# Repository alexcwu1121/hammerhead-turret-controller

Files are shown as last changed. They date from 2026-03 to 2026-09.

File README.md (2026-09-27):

# hammerhead-turret-controller

To build:
1. Install Podman >4.x
2. Install VSCode
3. Install VSCode Dev Containers extension
4. In Dev Containers settings, set the following:
    - Docker Path: `podman`
    - Docker Compose Path: `podman-compose`
    - Docker Socket: `/run/podman/podman.sock`

To quick-run pre-commit, builds, tests:
`podman-compose run --build pre-commit`
`podman-compose run --build build-debug`
`podman-compose run --build build-release`

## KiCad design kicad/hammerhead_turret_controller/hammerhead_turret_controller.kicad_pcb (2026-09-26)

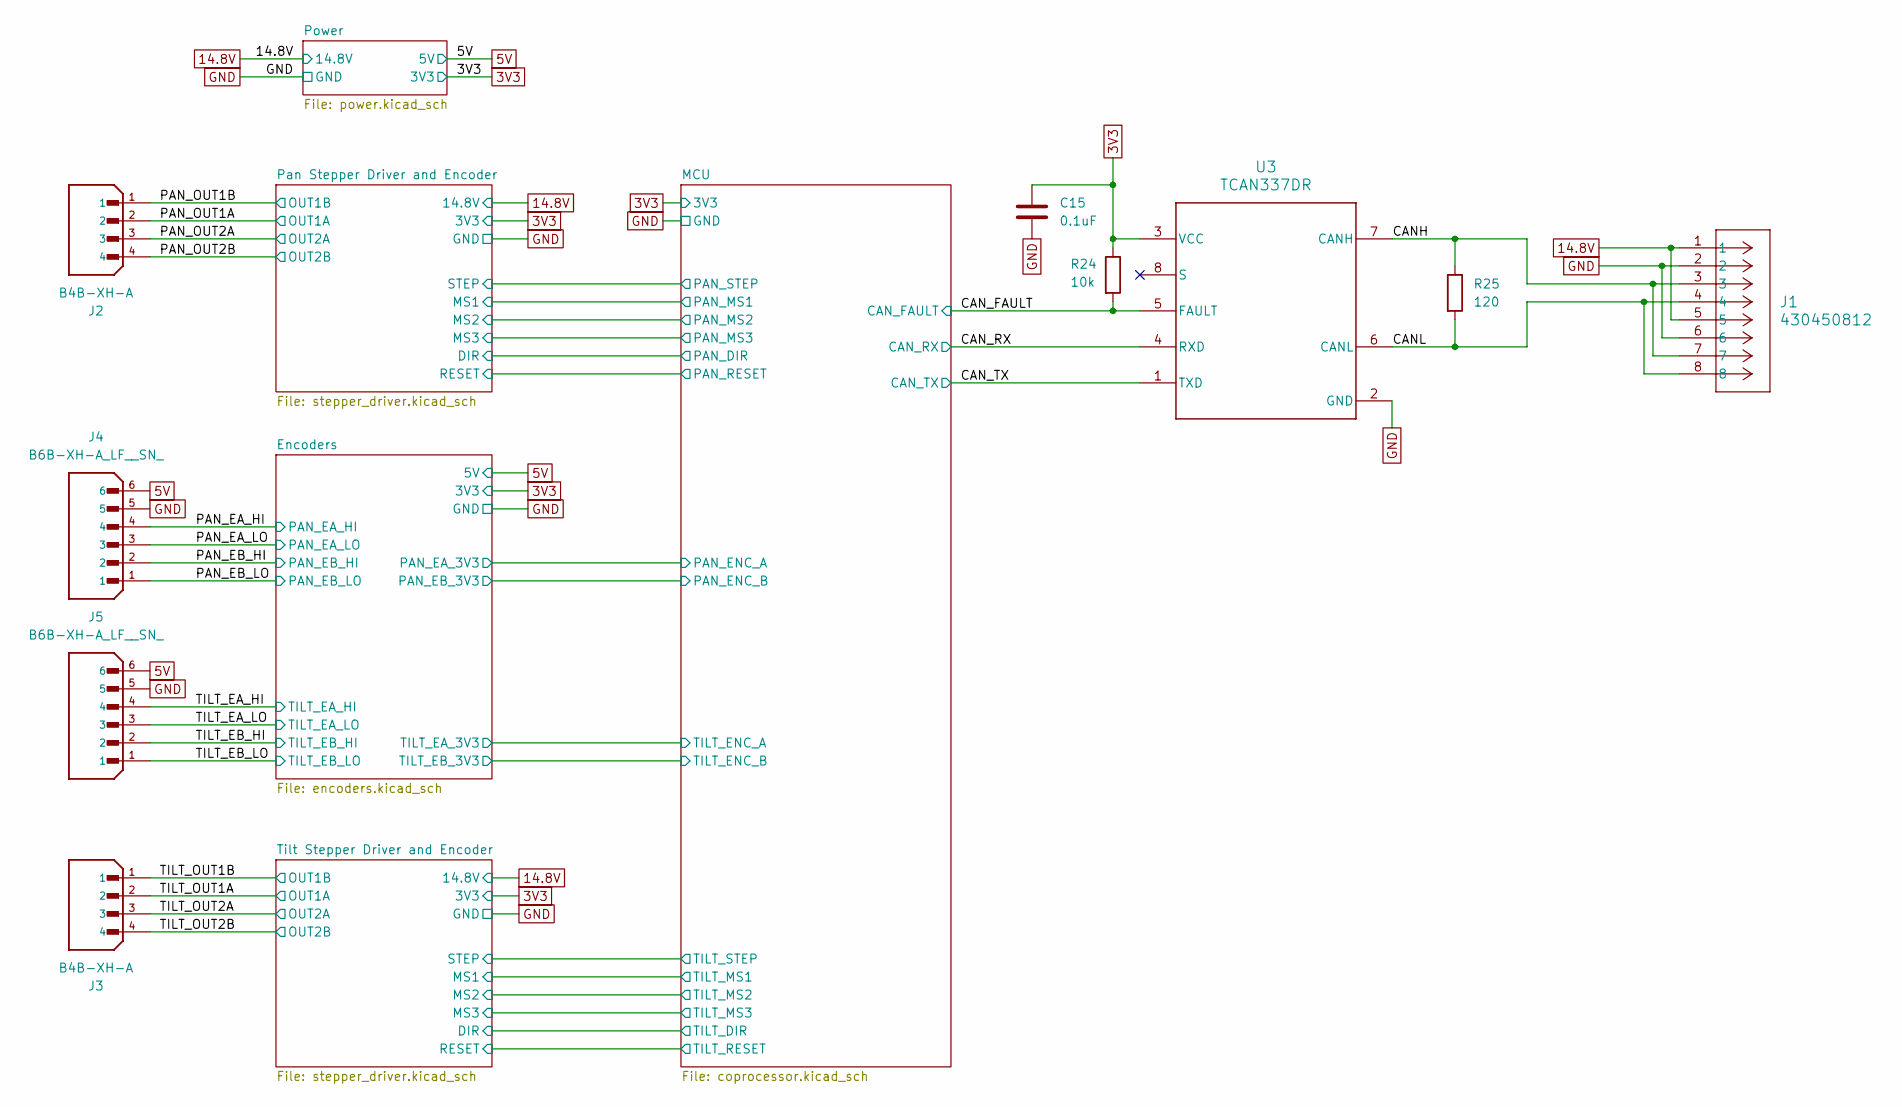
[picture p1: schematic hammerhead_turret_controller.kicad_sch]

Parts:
C15: 0.1uF; C_0402_1005Metric
J1: 430450812; CONN_SD-43045-005_08_MOL
J2, J3: B4B-XH-A; JST_ZH_S4B-ZR-SM4A-TF_1x04-1MP_P1.50mm_Horizontal; PARTREV 7/4/21; DigiKey_Part_Number 455-B4B-XH-A-ND
J4, J5: B6B-XH-A_LF__SN_; JST_ZH_S6B-ZR-SM4A-TF_1x06-1MP_P1.50mm_Horizontal; PARTREV 7/4/21
R24: 10k; R_0402_1005Metric
R25: 120; R_0603_1608Metric
U3: TCAN337DR; D0008A_N

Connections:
3V3: C15.1, R24.1, U3.3 (VCC); also elsewhere on the board
5V: J4.6, J5.6; also elsewhere on the board
14.8V: J1.1, J1.5; also elsewhere on the board
/CANH: J1.3, J1.7, R25.1, U3.7 (CANH)
/CANL: J1.4, J1.8, R25.2, U3.6 (CANL)
/CAN_FAULT: R24.2, U3.5 (FAULT); also elsewhere on the board
/CAN_RX: U3.4 (RXD); also elsewhere on the board
/CAN_TX: U3.1 (TXD); also elsewhere on the board
/PAN_EA_HI: J4.4; also elsewhere on the board
/PAN_EA_LO: J4.3; also elsewhere on the board
/PAN_EB_HI: J4.2; also elsewhere on the board
/PAN_EB_LO: J4.1; also elsewhere on the board
/PAN_OUT1A: J2.2; also elsewhere on the board
/PAN_OUT1B: J2.1; also elsewhere on the board
/PAN_OUT2A: J2.3; also elsewhere on the board
/PAN_OUT2B: J2.4; also elsewhere on the board
/TILT_EA_HI: J5.4; also elsewhere on the board
/TILT_EA_LO: J5.3; also elsewhere on the board
/TILT_EB_HI: J5.2; also elsewhere on the board
/TILT_EB_LO: J5.1; also elsewhere on the board
/TILT_OUT1A: J3.2; also elsewhere on the board
/TILT_OUT1B: J3.1; also elsewhere on the board
/TILT_OUT2A: J3.3; also elsewhere on the board
/TILT_OUT2B: J3.4; also elsewhere on the board
GND: C15.2, J1.2, J1.6, J4.5, J5.5, U3.2 (GND); also elsewhere on the board

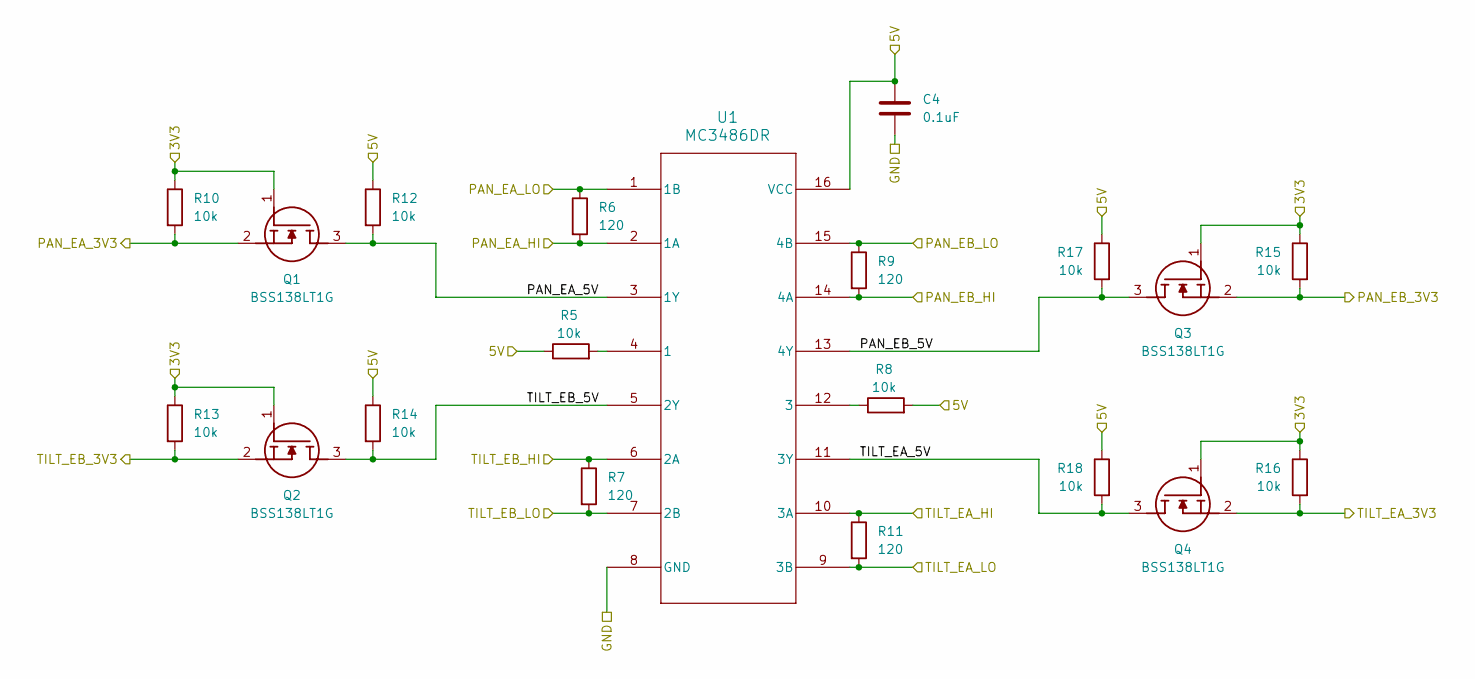
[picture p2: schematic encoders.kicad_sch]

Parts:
C4: 0.1uF; C_0201_0603Metric
Q1, Q2, Q3, Q4: BSS138LT1G; SOT96P237X111-3N; Manufacturer_Part_Number BSS138LT1G; Mouser Part Number 863-BSS138LT1G
R5, R8, R10, R12, R13, R14, R15, R16, R17, R18: 10k; R_0201_0603Metric
R6, R7, R9, R11: 120; R_0201_0603Metric
U1: MC3486DR; D16

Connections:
3V3: Q1.1 (G), Q2.1 (G), Q3.1 (G), Q4.1 (G), R10.1, R13.1, R15.1, R16.1; also elsewhere on the board
5V: C4.2, R5.1, R8.2, R12.1, R14.1, R17.1, R18.1, U1.16 (VCC); also elsewhere on the board
/Encoders/PAN_EA_5V: Q1.3 (D), R12.2, U1.3 (1Y)
/Encoders/PAN_EB_5V: Q3.3 (D), R17.2, U1.13 (4Y)
/Encoders/TILT_EA_5V: Q4.3 (D), R18.2, U1.11 (3Y)
/Encoders/TILT_EB_5V: Q2.3 (D), R14.2, U1.5 (2Y)
/MCU/PAN_ENC_A: Q1.2 (S), R10.2; also elsewhere on the board
/MCU/PAN_ENC_B: Q3.2 (S), R15.2; also elsewhere on the board
/MCU/TILT_ENC_A: Q4.2 (S), R16.2; also elsewhere on the board
/MCU/TILT_ENC_B: Q2.2 (S), R13.2; also elsewhere on the board
/PAN_EA_HI: R6.2, U1.2 (1A); also elsewhere on the board
/PAN_EA_LO: R6.1, U1.1 (1B); also elsewhere on the board
/PAN_EB_HI: R9.2, U1.14 (4A); also elsewhere on the board
/PAN_EB_LO: R9.1, U1.15 (4B); also elsewhere on the board
/TILT_EA_HI: R11.1, U1.10 (3A); also elsewhere on the board
/TILT_EA_LO: R11.2, U1.9 (3B); also elsewhere on the board
/TILT_EB_HI: R7.1, U1.6 (2A); also elsewhere on the board
/TILT_EB_LO: R7.2, U1.7 (2B); also elsewhere on the board
GND: C4.1, U1.8 (GND); also elsewhere on the board
unnamed: R5.2, U1.4 (1)
unnamed: R8.1, U1.12 (3)

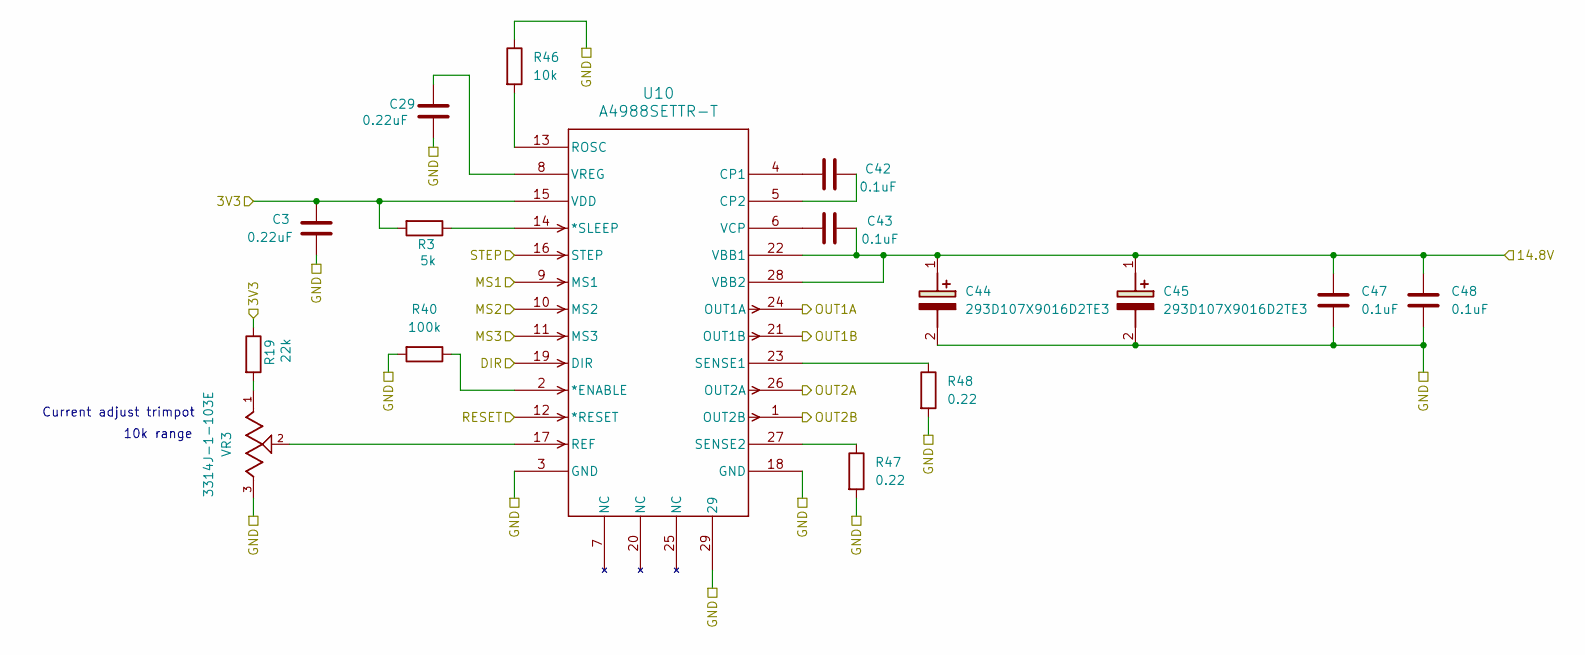
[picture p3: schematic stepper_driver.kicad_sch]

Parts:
C3: 0.22uF; C_0201_0603Metric
C29: 0.22uF; C_0402_1005Metric
C42, C43: 0.1uF; C_0201_0603Metric
C44, C45: 293D107X9016D2TE3; CAPPM7343X310N; Manufacturer_Part_Number 293D107X9016D2TE3; Mouser Part Number 74-293D107X9016D2TE3
C47, C48: 0.1uF; C_0603_1608Metric
R3: 5k; R_0201_0603Metric
R19: 22k; R_0201_0603Metric
R40: 100k; R_0201_0603Metric
R46: 10k; R_0402_1005Metric
R47, R48: 0.22; R_0402_1005Metric
U10: A4988SETTR-T; QFN-28_ALM
VR3: 3314J-1-103E; TRIM_3314J-1-103E

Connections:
3V3: C3.2, R3.2, R19.1, U10.15 (VDD); also elsewhere on the board
14.8V: C43.2, C44.1 (+), C45.1 (+), C47.1, C48.1, U10.22 (VBB1), U10.28 (VBB2); also elsewhere on the board
/MCU/PAN_DIR: U10.19 (DIR); also elsewhere on the board
/MCU/PAN_MS1: U10.9 (MS1); also elsewhere on the board
/MCU/PAN_MS2: U10.10 (MS2); also elsewhere on the board
/MCU/PAN_MS3: U10.11 (MS3); also elsewhere on the board
/MCU/PAN_RESET: U10.12 (*RESET); also elsewhere on the board
/MCU/PAN_STEP: U10.16 (STEP); also elsewhere on the board
/PAN_OUT1A: U10.24 (OUT1A); also elsewhere on the board
/PAN_OUT1B: U10.21 (OUT1B); also elsewhere on the board
/PAN_OUT2A: U10.26 (OUT2A); also elsewhere on the board
/PAN_OUT2B: U10.1 (OUT2B); also elsewhere on the board
GND: C3.1, C29.2, C44.2 (-), C45.2 (-), C47.2, C48.2, R40.2, R46.1, R47.2, R48.2, U10.3 (GND), U10.18 (GND), U10.29, VR3.3; also elsewhere on the board
unnamed: R19.2, VR3.1
unnamed: R40.1, U10.2 (*ENABLE)
unnamed: R3.1, U10.14 (*SLEEP)
unnamed: C42.1, U10.4 (CP1)
unnamed: C42.2, U10.5 (CP2)
unnamed: U10.17 (REF), VR3.2
unnamed: R46.2, U10.13 (ROSC)
unnamed: R48.1, U10.23 (SENSE1)
unnamed: R47.1, U10.27 (SENSE2)
unnamed: C43.1, U10.6 (VCP)
unnamed: C29.1, U10.8 (VREG)

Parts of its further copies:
C49: 0.22uF; C_0201_0603Metric
C51: 0.22uF; C_0402_1005Metric
C52, C53: 0.1uF; C_0201_0603Metric
C54, C55: 293D107X9016D2TE3; CAPPM7343X310N; Manufacturer_Part_Number 293D107X9016D2TE3; Mouser Part Number 74-293D107X9016D2TE3
C57, C58: 0.1uF; C_0603_1608Metric
R4: 5k; R_0201_0603Metric
R26: 22k; R_0201_0603Metric
R52: 100k; R_0201_0603Metric
R58: 10k; R_0402_1005Metric
R59, R60: 0.22; R_0402_1005Metric
U13: A4988SETTR-T; QFN-28_ALM
VR4: 3314J-1-103E; TRIM_3314J-1-103E

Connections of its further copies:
3V3: C49.2, R4.2, R26.1, U13.15 (VDD); also elsewhere on the board
14.8V: C53.2, C54.1 (+), C55.1 (+), C57.1, C58.1, U13.22 (VBB1), U13.28 (VBB2); also elsewhere on the board
/MCU/TILT_DIR: U13.19 (DIR); also elsewhere on the board
/MCU/TILT_MS1: U13.9 (MS1); also elsewhere on the board
/MCU/TILT_MS2: U13.10 (MS2); also elsewhere on the board
/MCU/TILT_MS3: U13.11 (MS3); also elsewhere on the board
/MCU/TILT_RESET: U13.12 (*RESET); also elsewhere on the board
/MCU/TILT_STEP: U13.16 (STEP); also elsewhere on the board
/TILT_OUT1A: U13.24 (OUT1A); also elsewhere on the board
/TILT_OUT1B: U13.21 (OUT1B); also elsewhere on the board
/TILT_OUT2A: U13.26 (OUT2A); also elsewhere on the board
/TILT_OUT2B: U13.1 (OUT2B); also elsewhere on the board
GND: C49.1, C51.2, C54.2 (-), C55.2 (-), C57.2, C58.2, R52.2, R58.1, R59.2, R60.2, U13.3 (GND), U13.18 (GND), U13.29, VR4.3; also elsewhere on the board
unnamed: R26.2, VR4.1
unnamed: R52.1, U13.2 (*ENABLE)
unnamed: R4.1, U13.14 (*SLEEP)
unnamed: C52.1, U13.4 (CP1)
unnamed: C52.2, U13.5 (CP2)
unnamed: U13.17 (REF), VR4.2
unnamed: R58.2, U13.13 (ROSC)
unnamed: R60.1, U13.23 (SENSE1)
unnamed: R59.1, U13.27 (SENSE2)
unnamed: C53.1, U13.6 (VCP)
unnamed: C51.1, U13.8 (VREG)

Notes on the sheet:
Current adjust trimpot
10k range

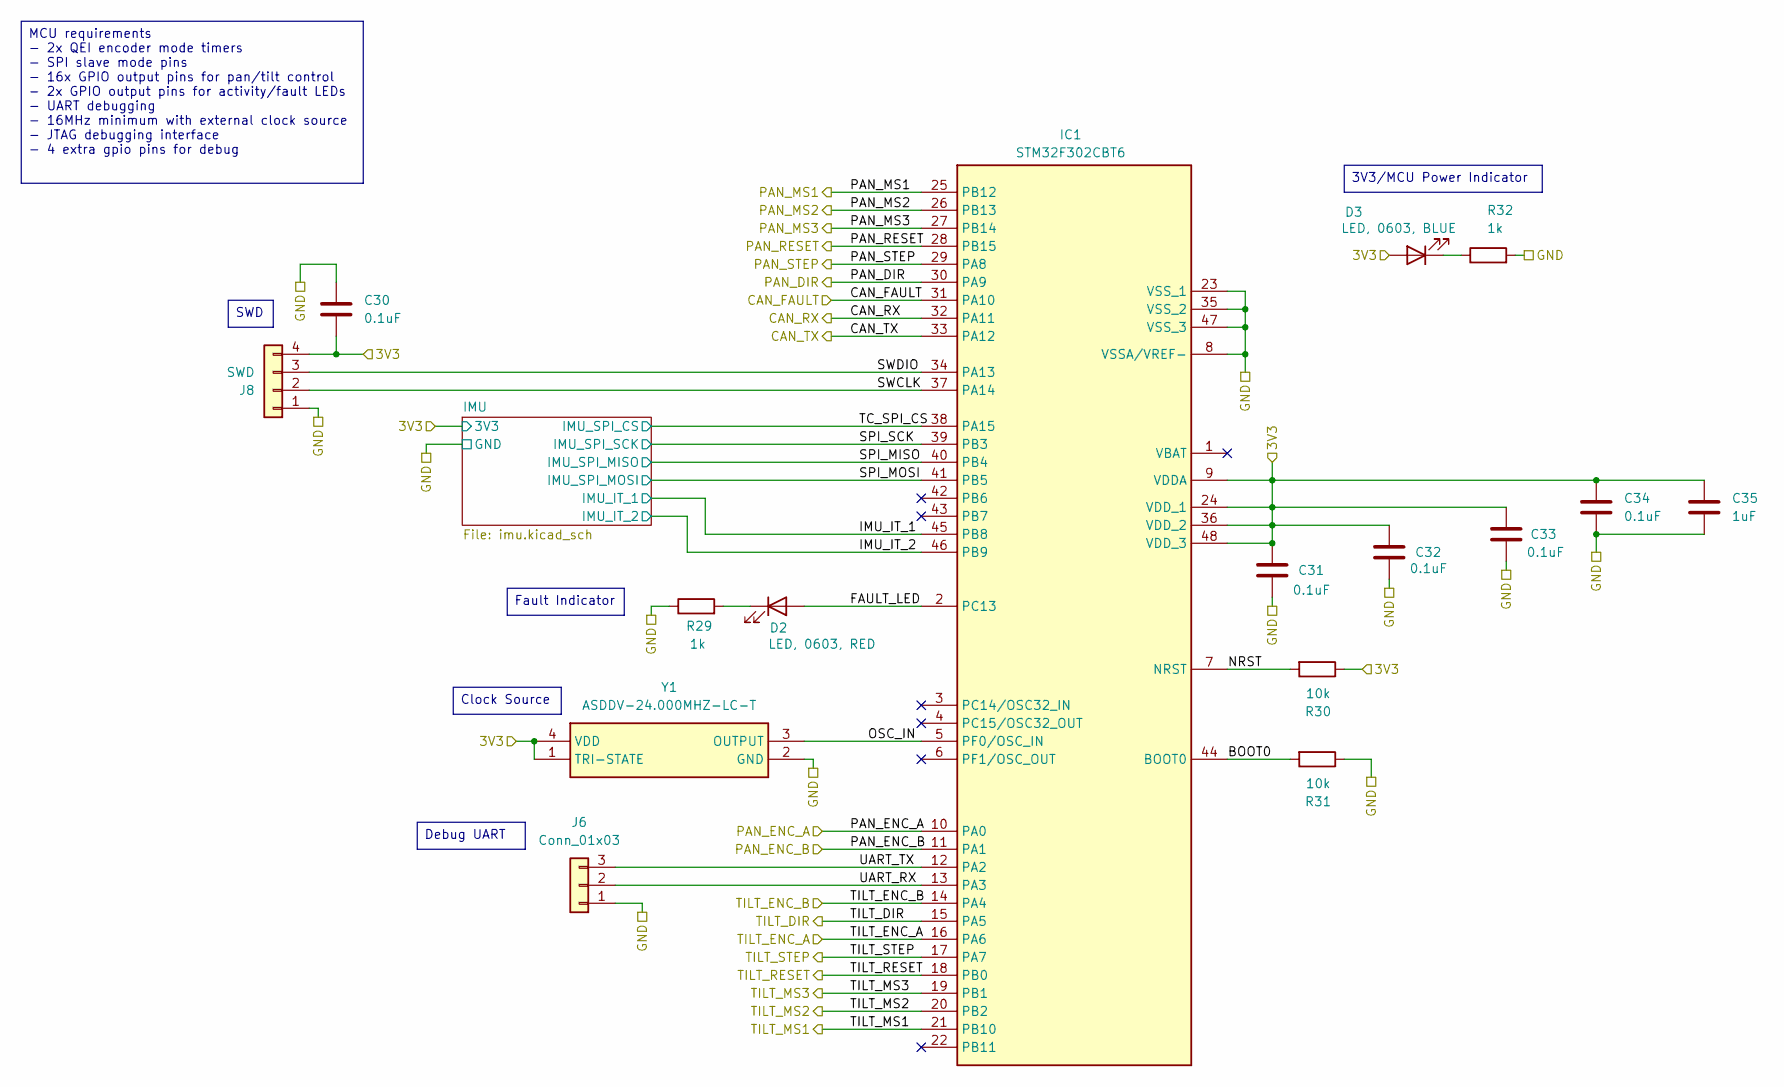
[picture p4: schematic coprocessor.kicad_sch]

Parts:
C30, C31, C32, C33, C34: 0.1uF; C_0201_0603Metric
C35: 1uF; C_0201_0603Metric
D2: LED, 0603, RED; D_0603_1608Metric
D3: LED, 0603, BLUE; D_0603_1608Metric
IC1: STM32F302CBT6; QFP50P900X900X160-48N; Manufacturer_Part_Number STM32F302CBT6; Mouser Part Number 511-STM32F302CBT6
J6: Conn_01x03; PinHeader_1x03_P1.00mm_Vertical
J8: SWD; PinHeader_1x04_P2.54mm_Vertical
R29: 1k; R_0201_0603Metric
R30, R31: 10k; R_0201_0603Metric
R32: 1k; R_0603_1608Metric
Y1: ASDDV-24.000MHZ-LC-T; AbraconASDDV; Manufacturer_Part_Number ASDDV-24.000MHZ-LC-T; Mouser Part Number 815-ASDDV-2400MHZLCT

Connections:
3V3: C30.1, C31.1, C32.1, C33.1, C34.1, C35.1, D3.2 (A), IC1.9 (VDDA), IC1.24 (VDD_1), IC1.36 (VDD_2), IC1.48 (VDD_3), J8.4, R30.1, Y1.1 (TRI-STATE), Y1.4 (VDD); also elsewhere on the board
/CAN_FAULT: IC1.31 (PA10); also elsewhere on the board
/CAN_RX: IC1.32 (PA11); also elsewhere on the board
/CAN_TX: IC1.33 (PA12); also elsewhere on the board
/MCU/BOOT0: IC1.44 (BOOT0), R31.2
/MCU/FAULT_LED: D2.2 (A), IC1.2 (PC13)
/MCU/IMU_IT_1: IC1.45 (PB8); also elsewhere on the board
/MCU/IMU_IT_2: IC1.46 (PB9); also elsewhere on the board
/MCU/NRST: IC1.7 (NRST), R30.2
/MCU/OSC_IN: IC1.5 (PF0/OSC_IN), Y1.3 (OUTPUT)
/MCU/PAN_DIR: IC1.30 (PA9); also elsewhere on the board
/MCU/PAN_ENC_A: IC1.10 (PA0); also elsewhere on the board
/MCU/PAN_ENC_B: IC1.11 (PA1); also elsewhere on the board
/MCU/PAN_MS1: IC1.25 (PB12); also elsewhere on the board
/MCU/PAN_MS2: IC1.26 (PB13); also elsewhere on the board
/MCU/PAN_MS3: IC1.27 (PB14); also elsewhere on the board
/MCU/PAN_RESET: IC1.28 (PB15); also elsewhere on the board
/MCU/PAN_STEP: IC1.29 (PA8); also elsewhere on the board
/MCU/SPI_MISO: IC1.40 (PB4); also elsewhere on the board
/MCU/SPI_MOSI: IC1.41 (PB5); also elsewhere on the board
/MCU/SPI_SCK: IC1.39 (PB3); also elsewhere on the board
/MCU/SWCLK: IC1.37 (PA14), J8.2
/MCU/SWDIO: IC1.34 (PA13), J8.3
/MCU/TC_SPI_CS: IC1.38 (PA15); also elsewhere on the board
/MCU/TILT_DIR: IC1.15 (PA5); also elsewhere on the board
/MCU/TILT_ENC_A: IC1.16 (PA6); also elsewhere on the board
/MCU/TILT_ENC_B: IC1.14 (PA4); also elsewhere on the board
/MCU/TILT_MS1: IC1.21 (PB10); also elsewhere on the board
/MCU/TILT_MS2: IC1.20 (PB2); also elsewhere on the board
/MCU/TILT_MS3: IC1.19 (PB1); also elsewhere on the board
/MCU/TILT_RESET: IC1.18 (PB0); also elsewhere on the board
/MCU/TILT_STEP: IC1.17 (PA7); also elsewhere on the board
/MCU/UART_RX: IC1.13 (PA3), J6.2
/MCU/UART_TX: IC1.12 (PA2), J6.3
GND: C30.2, C31.2, C32.2, C33.2, C34.2, C35.2, IC1.8 (VSSA/VREF-), IC1.23 (VSS_1), IC1.35 (VSS_2), IC1.47 (VSS_3), J6.1, J8.1, R29.1, R31.1, R32.2, Y1.2 (GND); also elsewhere on the board
unnamed: D2.1 (K), R29.2
unnamed: D3.1 (K), R32.1

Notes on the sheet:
Debug UART
3V3/MCU Power Indicator
Clock Source
MCU requirements - 2x QEI encoder mode timers - SPI slave mode pins - 16x GPIO output pins for pan/tilt control - 2x GPIO output pins for activity/fault LEDs - UART debugging - 16MHz minimum with external clock source - JTAG debugging interface - 4 extra gpio pins for debug
Fault Indicator
SWD

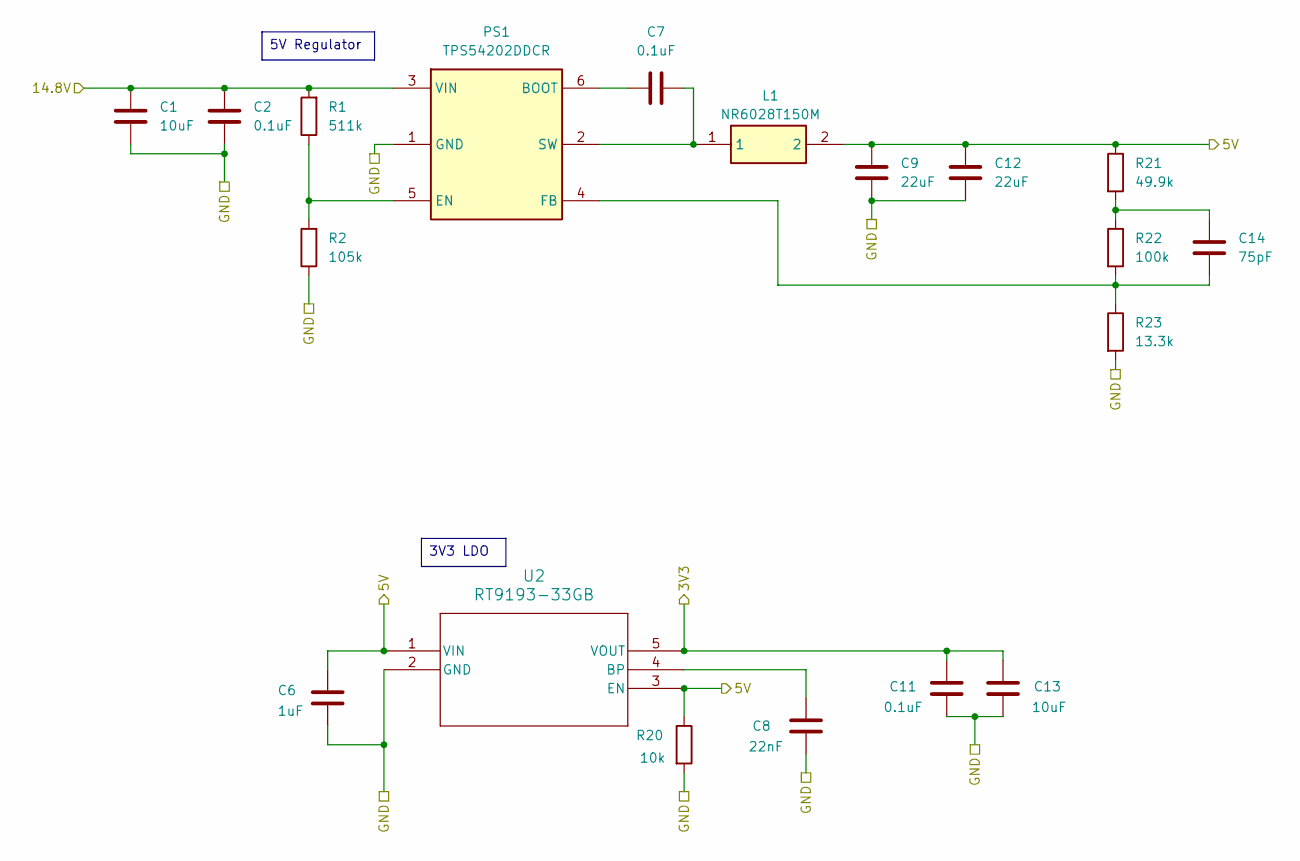
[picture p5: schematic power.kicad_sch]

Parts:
C1: 10uF; C_1206_3216Metric
C2, C7: 0.1uF; C_0201_0603Metric
C6: 1uF; C_0603_1608Metric
C8: 22nF; C_0402_1005Metric
C9, C12: 22uF; C_1206_3216Metric
C11: 0.1uF; C_0402_1005Metric
C13: 10uF; C_0603_1608Metric
C14: 75pF; C_0201_0603Metric
L1: NR6028T150M; Manufacturer_Part_Number NR6028T150M; Mouser Part Number 963-NR6028T150M
PS1: TPS54202DDCR; SOT95P280X110-6N; Manufacturer_Part_Number TPS54202DDCR; Mouser Part Number 595-TPS54202DDCR
R1: 511k; R_0201_0603Metric
R2: 105k; R_0201_0603Metric
R20: 10k; R_0402_1005Metric
R21: 49.9k; R_0201_0603Metric
R22: 100k; R_0201_0603Metric
R23: 13.3k; R_0201_0603Metric
U2: RT9193-33GB; SOT-23-5_RIT

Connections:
3V3: C11.2, C13.2, U2.5 (VOUT); also elsewhere on the board
5V: C6.2, C9.1, C12.1, L1.2, R20.1, R21.1, U2.1 (VIN), U2.3 (EN); also elsewhere on the board
14.8V: C1.1, C2.1, PS1.3 (VIN), R1.2; also elsewhere on the board
GND: C1.2, C2.2, C6.1, C8.1, C9.2, C11.1, C12.2, C13.1, PS1.1 (GND), R2.1, R20.2, R23.2, U2.2 (GND); also elsewhere on the board
unnamed: C14.1, R21.2, R22.1
unnamed: C7.1, PS1.6 (BOOT)
unnamed: PS1.5 (EN), R1.1, R2.2
unnamed: C14.2, PS1.4 (FB), R22.2, R23.1
unnamed: C7.2, L1.1, PS1.2 (SW)
unnamed: C8.2, U2.4 (BP)

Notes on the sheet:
5V Regulator
3V3 LDO

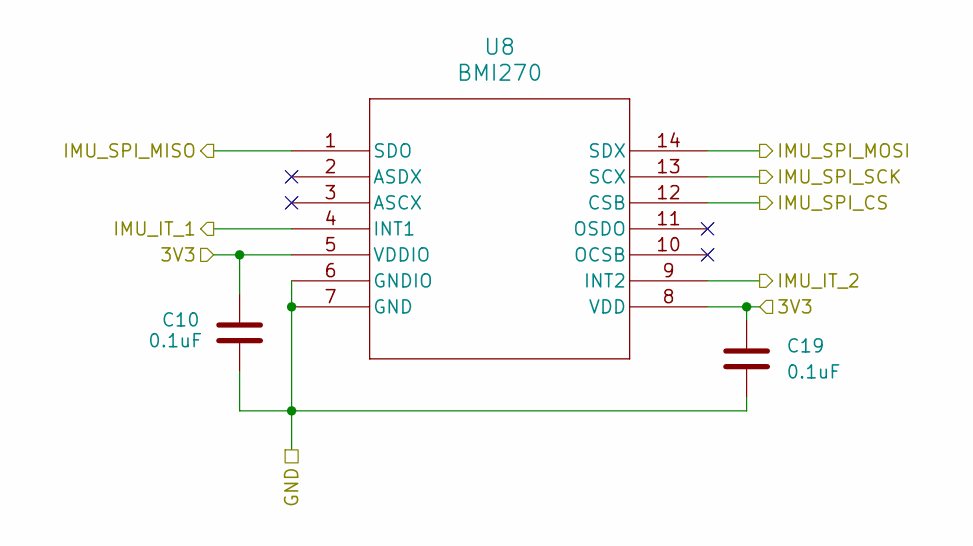
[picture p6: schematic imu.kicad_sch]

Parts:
C10, C19: 0.1uF; C_0402_1005Metric
U8: BMI270; BMI270_BOS

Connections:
3V3: C10.1, C19.2, U8.5 (VDDIO), U8.8 (VDD); also elsewhere on the board
/MCU/IMU_IT_1: U8.4 (INT1); also elsewhere on the board
/MCU/IMU_IT_2: U8.9 (INT2); also elsewhere on the board
/MCU/SPI_MISO: U8.1 (SDO); also elsewhere on the board
/MCU/SPI_MOSI: U8.14 (SDX); also elsewhere on the board
/MCU/SPI_SCK: U8.13 (SCX); also elsewhere on the board
/MCU/TC_SPI_CS: U8.12 (CSB); also elsewhere on the board
GND: C10.2, C19.1, U8.6 (GNDIO), U8.7 (GND); also elsewhere on the board

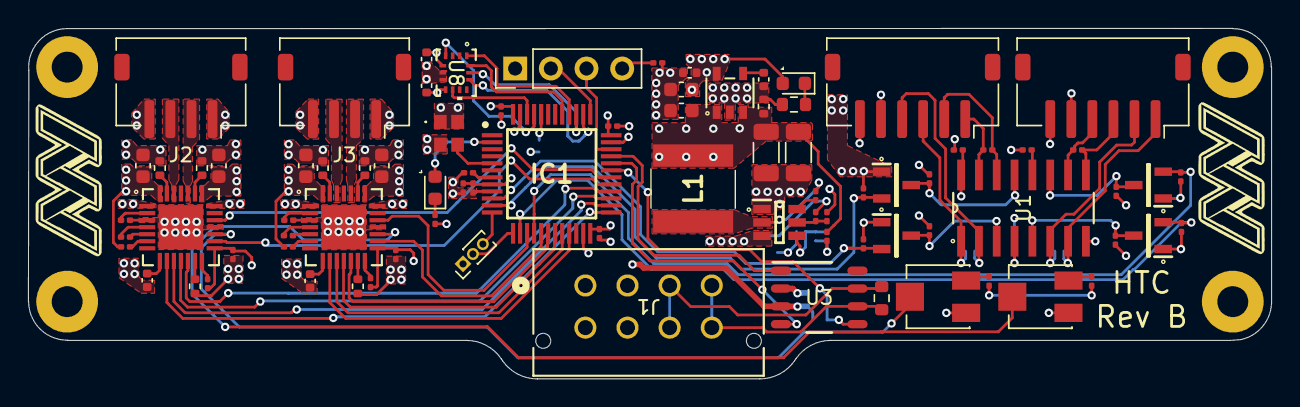
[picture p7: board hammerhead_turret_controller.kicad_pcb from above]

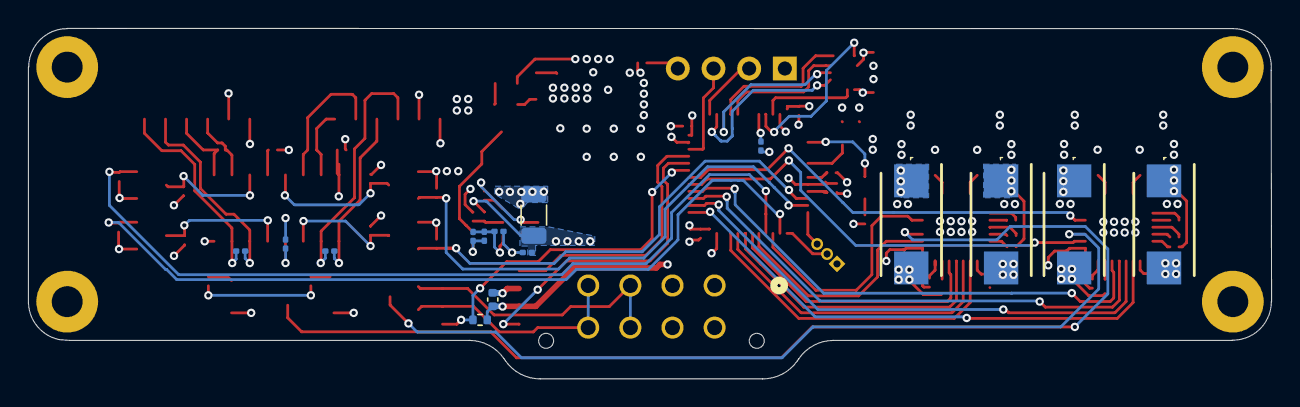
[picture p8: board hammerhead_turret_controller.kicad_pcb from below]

Board: 4 copper layers, 88.5 x 25.0 mm, 99 parts (15 on the bottom side), 91 nets.

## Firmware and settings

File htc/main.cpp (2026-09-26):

#include "main.h"
#include "i2c.h"
#include "spi.h"
#include "tim.h"
#include "usart.h"
#include "gpio.h"
#include "bsp.hpp"
#include "stm32f3xx_it.h"

// electrical todo
// adjust vref of stepper drivers either with DAC or potentiometer
// add mounting support holes near power connector
// somehow add bigger uart debug pads
// Consider allowing PWMing of motor step pin
// Add testpoints
// Add 2 fan controllers
// Add temperature sensor

#include "bmi270.hpp"

int main(void)
{
  /* Reset of all peripherals, Initializes the Flash interface and the Systick. */
  HAL_Init();

  /* Configure the system clock */
  SystemClock_Config();

  /* Initialize all configured peripherals */
  MX_GPIO_Init();
  MX_I2C1_Init();
  MX_SPI3_Init();
  MX_TIM2_Init();
  MX_TIM3_Init();
  MX_TIM4_Init();
  MX_TIM6_Init();
  MX_USART2_UART_Init();

  HAL_GPIO_WritePin(PAN_RESET_GPIO_Port, PAN_RESET_Pin, GPIO_PIN_RESET);
  HAL_GPIO_WritePin(TILT_RESET_GPIO_Port, PAN_RESET_Pin, GPIO_PIN_RESET);

  /*
  HAL_GPIO_WritePin(PAN_RESET_GPIO_Port, PAN_RESET_Pin, GPIO_PIN_SET);
  HAL_GPIO_WritePin(PAN_DIR_GPIO_Port, PAN_DIR_Pin, GPIO_PIN_RESET);
  HAL_GPIO_WritePin(PAN_MS1_GPIO_Port, PAN_MS1_Pin, GPIO_PIN_RESET);
  HAL_GPIO_WritePin(PAN_MS2_GPIO_Port, PAN_MS2_Pin, GPIO_PIN_RESET);
  HAL_GPIO_WritePin(PAN_MS3_GPIO_Port, PAN_MS3_Pin, GPIO_PIN_RESET);
  
  HAL_GPIO_WritePin(TILT_RESET_GPIO_Port, TILT_RESET_Pin, GPIO_PIN_SET);
  HAL_GPIO_WritePin(TILT_DIR_GPIO_Port, TILT_DIR_Pin, GPIO_PIN_RESET);
  HAL_GPIO_WritePin(TILT_MS1_GPIO_Port, TILT_MS1_Pin, GPIO_PIN_RESET);
  HAL_GPIO_WritePin(TILT_MS2_GPIO_Port, TILT_MS2_Pin, GPIO_PIN_RESET);
  HAL_GPIO_WritePin(TILT_MS3_GPIO_Port, TILT_MS3_Pin, GPIO_PIN_RESET);

  HAL_NVIC_SetPriority(TIM4_IRQn, 3, 0);
  HAL_NVIC_EnableIRQ(TIM4_IRQn);
  HAL_NVIC_SetPriority(TIM6_DAC_IRQn, 3, 0);
  HAL_NVIC_EnableIRQ(TIM6_DAC_IRQn);

  HAL_TIM_Base_Start_IT(&htim4);
  HAL_TIM_Base_Start_IT(&htim6);
  */

  //__HAL_TIM_SET_AUTORELOAD(&htim4, 9999);

  HAL_TIM_Encoder_Start(&htim2, TIM_CHANNEL_ALL);
  HAL_TIM_Encoder_Start(&htim3, TIM_CHANNEL_ALL);

  // Initialize IMU
  imu::BMI270 _imu(SPI_CS_GPIO_Port, SPI_CS_Pin, &hspi3);

  // Verify IMU device ID and enable SPI peripheral
  volatile imu::Fault fault = _imu.Initialize();
  fault = _imu.Initialize();

  // Set accelerometer ODR
  fault = _imu.SetAccODR(imu::BMI270::AccODR::ODR_800);

  // Set accelerometer range
  fault = _imu.SetAccRange(imu::BMI270::AccRange::G_4);

  // Set gyroscope ODR
  fault = _imu.SetGyrODR(imu::BMI270::GyrODR::ODR_1K6);

  // Set gyroscope range
  fault = _imu.SetGyrRange(imu::BMI270::GyrRange::DPS_500);

  fault = _imu.RunCompensation();

  imu::IMUData imu_data;
  while (1)
  {
    volatile uint32_t pan_pos = __HAL_TIM_GET_COUNTER(&htim2);
    volatile uint32_t tilt_pos = __HAL_TIM_GET_COUNTER(&htim3);
    
    imu::Fault fault = _imu.ReadData(imu_data);
    HAL_Delay(1);
    //HAL_GPIO_WritePin(PAN_STEP_GPIO_Port, PAN_STEP_Pin, GPIO_PIN_RESET);
    //HAL_GPIO_WritePin(TILT_STEP_GPIO_Port, TILT_STEP_Pin, GPIO_PIN_RESET);
    //HAL_Delay(1);
    //HAL_GPIO_WritePin(PAN_STEP_GPIO_Port, PAN_STEP_Pin, GPIO_PIN_SET);
    //HAL_GPIO_WritePin(TILT_STEP_GPIO_Port, TILT_STEP_Pin, GPIO_PIN_SET);
  }
}

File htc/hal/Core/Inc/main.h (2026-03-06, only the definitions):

#define FAULT_LED_Pin GPIO_PIN_13
#define FAULT_LED_GPIO_Port GPIOC
#define PAN_ENC_A_Pin GPIO_PIN_0
#define PAN_ENC_A_GPIO_Port GPIOA
#define PAN_ENC_B_Pin GPIO_PIN_1
#define PAN_ENC_B_GPIO_Port GPIOA
#define UART_TX_Pin GPIO_PIN_2
#define UART_TX_GPIO_Port GPIOA
#define UART_RX_Pin GPIO_PIN_3
#define UART_RX_GPIO_Port GPIOA
#define TILT_ENC_B_Pin GPIO_PIN_4
#define TILT_ENC_B_GPIO_Port GPIOA
#define TILT_DIR_Pin GPIO_PIN_5
#define TILT_DIR_GPIO_Port GPIOA
#define TILT_ENC_A_Pin GPIO_PIN_6
#define TILT_ENC_A_GPIO_Port GPIOA
#define TILT_STEP_Pin GPIO_PIN_7
#define TILT_STEP_GPIO_Port GPIOA
#define TILT_RESET_Pin GPIO_PIN_0
#define TILT_RESET_GPIO_Port GPIOB
#define TILT_MS3_Pin GPIO_PIN_1
#define TILT_MS3_GPIO_Port GPIOB
#define TILT_MS2_Pin GPIO_PIN_2
#define TILT_MS2_GPIO_Port GPIOB
#define TILT_MS1_Pin GPIO_PIN_10
#define TILT_MS1_GPIO_Port GPIOB
#define PAN_MS1_Pin GPIO_PIN_12
#define PAN_MS1_GPIO_Port GPIOB
#define PAN_MS2_Pin GPIO_PIN_13
#define PAN_MS2_GPIO_Port GPIOB
#define PAN_MS3_Pin GPIO_PIN_14
#define PAN_MS3_GPIO_Port GPIOB
#define PAN_RESET_Pin GPIO_PIN_15
#define PAN_RESET_GPIO_Port GPIOB
#define PAN_STEP_Pin GPIO_PIN_8
#define PAN_STEP_GPIO_Port GPIOA
#define PAN_DIR_Pin GPIO_PIN_9
#define PAN_DIR_GPIO_Port GPIOA
#define SPI_CS_Pin GPIO_PIN_15
#define SPI_CS_GPIO_Port GPIOA
#define SPI_SCK_Pin GPIO_PIN_3
#define SPI_SCK_GPIO_Port GPIOB
#define SPI_MISO_Pin GPIO_PIN_4
#define SPI_MISO_GPIO_Port GPIOB
#define SPI_MOSI_Pin GPIO_PIN_5
#define SPI_MOSI_GPIO_Port GPIOB
#define I2C_SCL_Pin GPIO_PIN_6
#define I2C_SCL_GPIO_Port GPIOB
#define I2C_SDA_Pin GPIO_PIN_7
#define I2C_SDA_GPIO_Port GPIOB
#define IMU_IT_1_Pin GPIO_PIN_8
#define IMU_IT_1_GPIO_Port GPIOB
#define IMU_IT_2_Pin GPIO_PIN_9
#define IMU_IT_2_GPIO_Port GPIOB

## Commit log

2026-02-25 add kicad design files
    [cm5_and_peripherals.kicad_sch, cm5_gpio.kicad_sch, cm5_high_speed.kicad_sch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]
2026-08-28 add can transceiver
    [coprocessor.kicad_sch, encoders.kicad_sch, hammerhead_turret_controller.kicad_pcb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]
2026-09-26 enable encoders, stepper drivers
2026-09-27 update htc ioc to use pll clock and enable PA7 and PA8 pwm generation
2026-09-27 git ignore kicad pcb lock files and backups
2026-09-27 update HAL, add imu and cli drivers and AOs
2026-09-28 add a4988 stepper driver and turret control ao
2026-09-30 add turret motor closed loop slew rate control mode, add control ao, add can comms
2026-10-01 rename turret directory to stepper
2026-10-03 add imu-stabilized position control and tilt homing state machine
    [bmi270.cpp, main.cpp]
2026-10-05 fix issue with in-ram chunk not getting written
    [main.cpp]
2026-10-07 add stepper telemetry messages and fix heartbeat timer never being started. also welcome claude.
2026-11-08 retune controllers after changing turret gearboxes from 20:1 to 50:1. add hi-pass attitude threshold for imu turret positionn compensation. add disable/enable motors and slew rate to cli and can inte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

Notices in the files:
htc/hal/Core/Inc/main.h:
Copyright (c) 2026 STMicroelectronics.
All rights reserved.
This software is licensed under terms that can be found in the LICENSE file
